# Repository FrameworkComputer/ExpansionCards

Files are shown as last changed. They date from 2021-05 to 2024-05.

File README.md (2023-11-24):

# Expansion Cards
Reference designs and documentation to create Expansion Cards for the Framework Laptop.
The Framework Laptop's Expansion Card system lets you choose exactly the ports you want
and which side you want them on.  We've built USB-C, USB-A, HDMI, DP, MicroSD, and Storage
Expansion Cards, but there is an entire world of other interesting ways to extend the
capabilities of a notebook.  We're releasing CAD to make it easy for you to develop your
own Expansion Cards.

Check out the Expansion Card section of the Framework Community for card ideas, support,
or just to show off what you're working on: https://community.frame.work/c/expansion-cards/developer-program/90

Note that you should build and test
development versions before committing a design based on this CAD to mass production.

MicrocontrollerExpansionCard

## License

Expansion Cards © 2021 by Framework Computer Inc is licensed under CC BY 4.0.
To view a copy of this license, visit http://creativecommons.org/licenses/by/4.0/

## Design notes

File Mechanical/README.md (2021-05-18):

# Expansion Card Mechanical CAD

## License

Expansion Cards © 2021 by Framework Computer Inc is licensed under CC BY 4.0.
To view a copy of this license, visit http://creativecommons.org/licenses/by/4.0/

## Files

There are a few variants of mechanical CAD that we have released:

 - OpenSCAD - This is a parametric model using OpenSCAD (https://openscad.org),
   designed to be easy to edit and 3D print.
   
 - Printable - These are 2D drawings and 3D CAD of an lid-less card enclosure
   that is designed to be easy to either 3D print, CNC, or injection mold.
   There is a version designed for use of self-tapping M2 screws, and also a
   version that can accomodate M2 threaded inserts.
   
 - Retrofit - This is a 2D drawing for a PCB that can be retrofit into existing
   Expansion Card cards sold by Framework.
   

## Getting Expansion Card Enclosures Fabricated

We've designed the enclosures to be printable on home 3D printers using PLA filament.

If you don't have a 3D printer, it's also easy to order enclosures from the various
printing services that are out there.  Because Expansion Cards are tiny, it is 
extremely inexpensive to get cards printed.  We haven't used all of the services below,
but these are some of the popular ones:
 - Shapeways (https://www.shapeways.com/) - HP MJF material
 - Hubs (https://www.hubs.com/) - HP MJF material (has a minimum order quantity)
 - Treatstock (https://www.treatstock.com/) - Range of materials, including PLA

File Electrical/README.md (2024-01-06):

# Expansion Card Electrical CAD

## License

Expansion Cards © 2021 by Framework Computer Inc is licensed under CC BY 4.0.
To view a copy of this license, visit http://creativecommons.org/licenses/by/4.0/

## Files

 - KiCad_templates - These are templates with the PCB outline and some basic components
   to let you get started with a card design quickly.  The Expansion_Card template
   is designed to be used with the 3D printable enclosures in the Mechanical folder.
   The Expansion_Card_Retrofit template is smaller and designed to fit into the existing
   Expansion Card enclosures like the DP Expansion Card's.  You can copy the folders to
   the default template directory: https://docs.kicad.org/5.0/en/kicad/kicad.html#template_locations
 - Microcontroller - A reference project using a SAMD21 Microcontroller with some pin
   headers broken out.  We've found Preci-Dip 8FM-78-0010-02-146 headers to fit well within the
   size constraints.  **Note:** We've built and done basic validation on an older version
   of this design, but the version currently in this repository is untested.
   

## Fabrication and Assembly

The templates and reference designs currently in this repository are basic, 2-layer, USB 2.0 designs.
This means the requirements around fabrication and assembly are pretty minimal.  Most PCB makers
and assemblers will be able to handle this.  We've listed a few popular ones below for reference.
Note that these are not necessarily vetted by Framework.

Note that there are pads next to the USB-C plug for manual soldering for additional strength.
You'll have to specify that to your assembler or hand solder that yourself.

PCB Only
 - OSHPark (https://oshpark.com/)

PCB+Assembly
 - Seeed (https://www.seeedstudio.com/fusion_pcb.html)
 - PCBWay (https://www.pcbway.com/pcb-assembly.html)
 - Macrofab (https://macrofab.com/)
 - Circuithub (https://circuithub.com/)

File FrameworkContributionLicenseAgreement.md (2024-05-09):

# Contribution License Agreement

This Contribution License Agreement (“Agreement”) is agreed to by the party signing (“You”), and conveys certain license rights to Framework Computer Inc and its affiliates (“Framework”) for Your contributions to Framework open source projects. This Agreement is effective as of the latest signature date.

1. Definitions.

   “Code” means the computer software code, whether in human-readable or machine-executable form, that is delivered by You to Framework under this Agreement.

   “Project” means any of the projects owned or managed by Framework in which software is offered under a license approved by the Open Source Initiative (OSI) (www.opensource.org) and documentation offered under an OSI or a Creative Commons license (https://creativecommons.org/licenses).

   “Submit” is the act of uploading, submitting, transmitting, or distributing code or other content to any Project, including but not limited to communication on electronic mailing lists, source code control systems, and issue tracking systems that are managed by, or on behalf of, the Project for the purpose of discussing and improving that Project, but excluding communication that is conspicuously marked or otherwise designated in writing by You as “Not a Submission.”

   “Submission” means the Code and any other copyrightable material Submitted by You, including any associated comments and documentation.

2. Your Submission. You must agree to the terms of this Agreement before making a Submission to any Project. This Agreement covers any and all Submissions that You, now or in the future (except as described in Section 4 below), Submit to any Project.

3. Originality of Work. You represent that each of Your Submissions is entirely Your original work. Should You wish to Submit materials that are not Your original work,You may Submit them separately to the Project if You (a) retain all copyright and license information that was in the materials as You received them, (b) in the description accompanying Your Submission, include the phrase “Submission containing materials of a third party:” followed by the names of the third party and any licenses or other restrictions of which You are aware, and (c) follow any other instructions in the Project’s written guidelines concerning Submissions.

4. Your Employer. References to “employer” in this Agreement include Your employer or anyone else for whom You are acting in making Your Submission, e.g. as a contractor, vendor, or agent. If Your Submission is made in the course of Your work for an employer or Your employer has intellectual property rights in Your Submission by contract or applicable law, You must secure permission from Your employer to make the Submission before signing this Agreement. In that case, the term “You” in this Agreement will refer to You and the employer collectively. If You change employers in the future and desire to Submit additional Submissions for the new employer,then You agree to sign a new Agreement and secure permission from the new employer before Submitting those Submissions.

5. Licenses.

   a. Copyright License. You grant Framework, and those who receive the Submission directly or indirectly from Framework, a perpetual, worldwide, non-exclusive, royalty-free, irrevocable license in the Submission to reproduce, prepare derivative works of, publicly display, publicly perform, and distribute the Submission and such derivative works, and to sublicense any or all of the foregoing rights to third parties.

   b. Patent License. You grant Framework, and those who receive the Submission directly or indirectly from Framework, a perpetual, worldwide, non-exclusive, royalty-free, irrevocable license under Your patent claims that are necessarily infringed by the Submission or the combination of the Submission with the Project to which it was Submitted to make, have made, use, offer to sell, sell and import or otherwise dispose of the Submission alone or with the Project.

   c. Other Rights Reserved. Each party reserves all rights not expressly granted in this Agreement. No additional licenses or rights whatsoever (including, without limitation, any implied licenses) are granted by implication, exhaustion, estoppel or otherwise.

6. Representations and Warranties. You represent that You are legally entitled to grant the above licenses.You represent that each of Your Submissions is entirely Your original work (except as You may have disclosed under Section 3). You represent that You have secured permission from Your employer to make the Submission in cases where Your Submission is made in the course of Your work for Your employer or Your employer has intellectual property rights in Your Submission by contract or applicable law. If You are signing this Agreement on behalf of Your employer, You represent and warrant that You have the necessary authority to bind the listed employer to the obligations contained in this Agreement. You are not expected to provide support for Your Submission, unless You choose to do so. UNLESS REQUIRED BY APPLICABLE LAW OR AGREED TO IN WRITING, AND EXCEPT FOR THE WARRANTIES EXPRESSLY STATED IN SECTIONS 3, 4, AND 6,THE SUBMISSION PROVIDED UNDER THIS AGREEMENT IS PROVIDED WITHOUT WARRANTY OF ANY KIND, INCLUDING, BUT NOT LIMITED TO, ANY WARRANTY OF NONINFRINGEMENT, MERCHANTABILITY, OR FITNESS FOR A PARTICULAR PURPOSE.

7. Notice to Framework. You agree to notify Framework in writing of any facts or circumstances of which You later become aware that would make Your representations in this Agreement inaccurate in any respect.

8. Information about Submissions. You agree that contributions to Projects and information about contributions may be maintained indefinitely and disclosed publicly, including Your name and other information that You submit with Your Submission.

9. Governing Law/Jurisdiction. This Agreement is governed by the laws of the State of California, and the parties consent to exclusive jurisdiction and venue in the federal courts sitting in San Francisco County, California, unless no federal subject matter jurisdiction exists, in which case the parties consent to exclusive jurisdiction and venue in the Superior Court of California. The parties waive all defenses of lack of personal jurisdiction and forum non-conveniens.

10. Entire Agreement/Assignment. This Agreement is the entire agreement between the parties, and supersedes any and all prior agreements, understandings or communications, written or oral, between the parties relating to the subject matter hereof. This Agreement may be assigned by Framework.

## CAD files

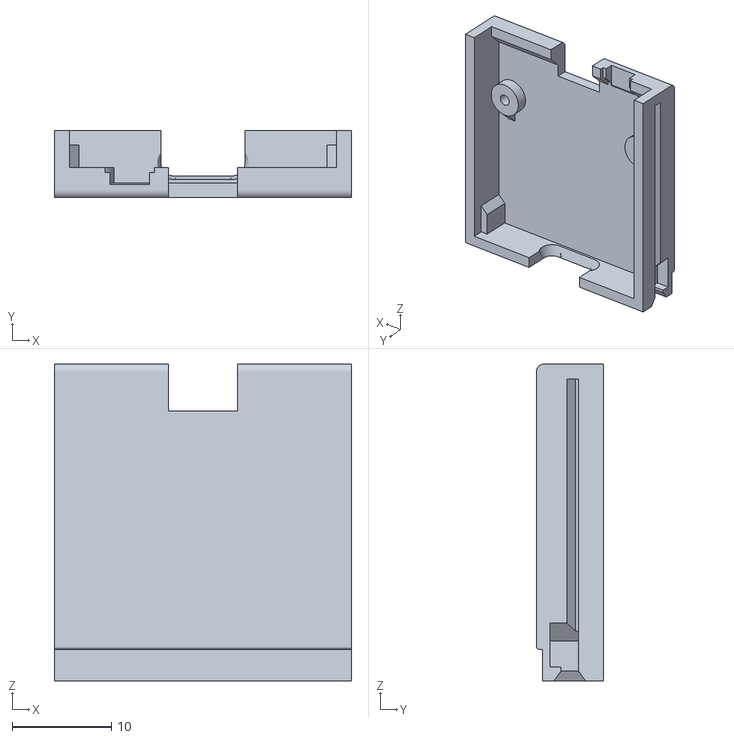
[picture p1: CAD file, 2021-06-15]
Mechanical/OpenSCAD/MicrocontrollerHousing.stl
30.0 x 6.80 x 32.0

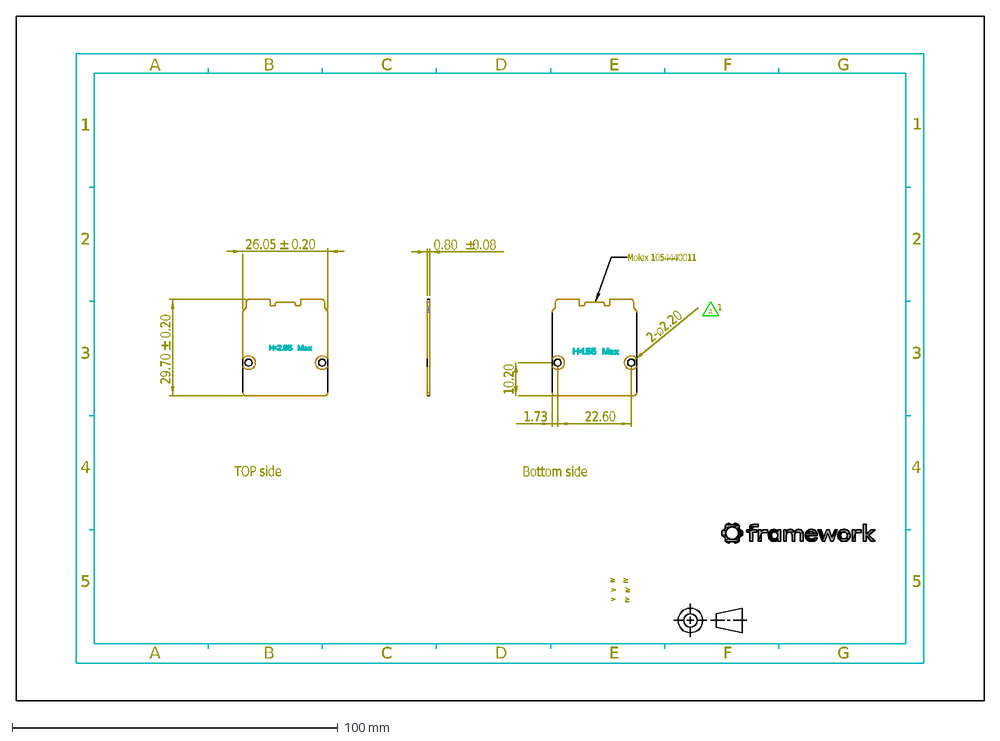
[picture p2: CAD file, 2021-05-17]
Mechanical/Printable/2D/ExpansionCard_Printable_M2.dxf
5
4
A
B
C
3
2
1
D
E
F
G
26.05
0.20
29.70
0.80
0.08
10.20
1.73
22.60
TOP side
Bottom side
Molex 1054440011

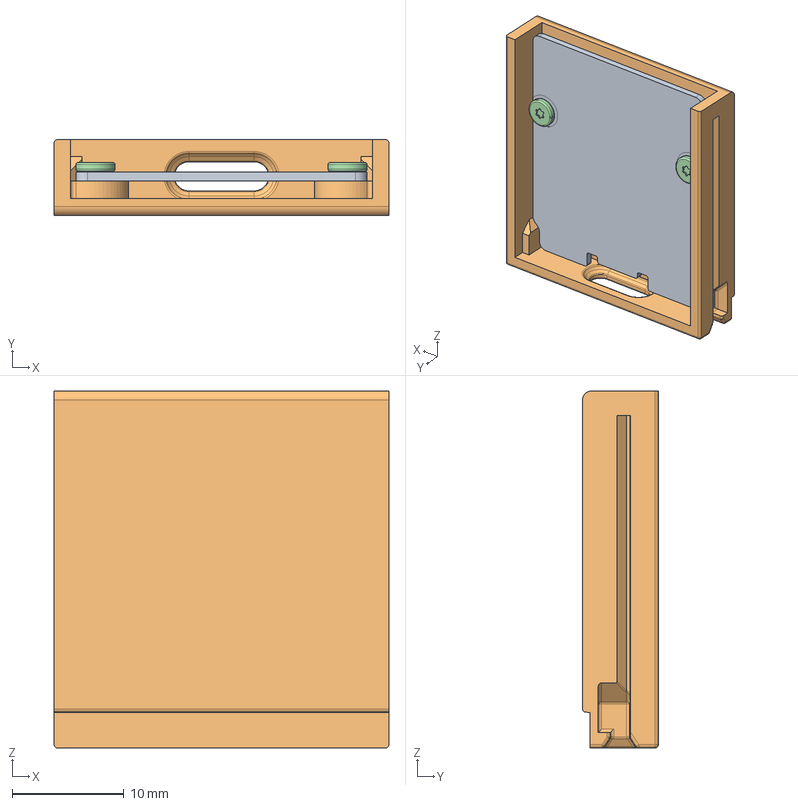
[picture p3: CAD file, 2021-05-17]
Mechanical/Printable/3D/ExpansionCard_ThreadedInsert.stp
30.0 x 6.80 x 32.0 mm
FW_EXP_1USBC_FRAME_CLIP_BC_229_
NUT_M2X1-6L_2 x 2
STAR_SCREW_M2X3L_298_2 x 2

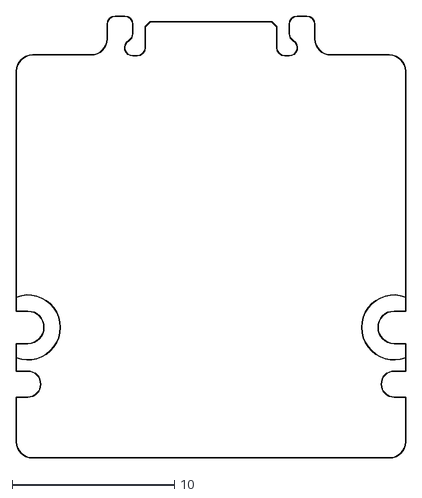
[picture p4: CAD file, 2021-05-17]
Mechanical/Retrofit/2D/ExpansionCard_Retrofit_Outline.dxf
24.0 x 27.2

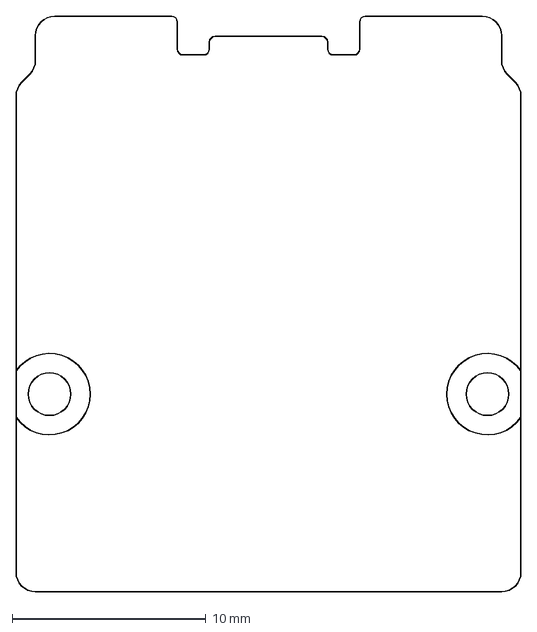
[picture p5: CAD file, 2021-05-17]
Mechanical/Printable/2D/ExpansionCard_Printable_Outline.dxf
26.1 x 29.7 mm

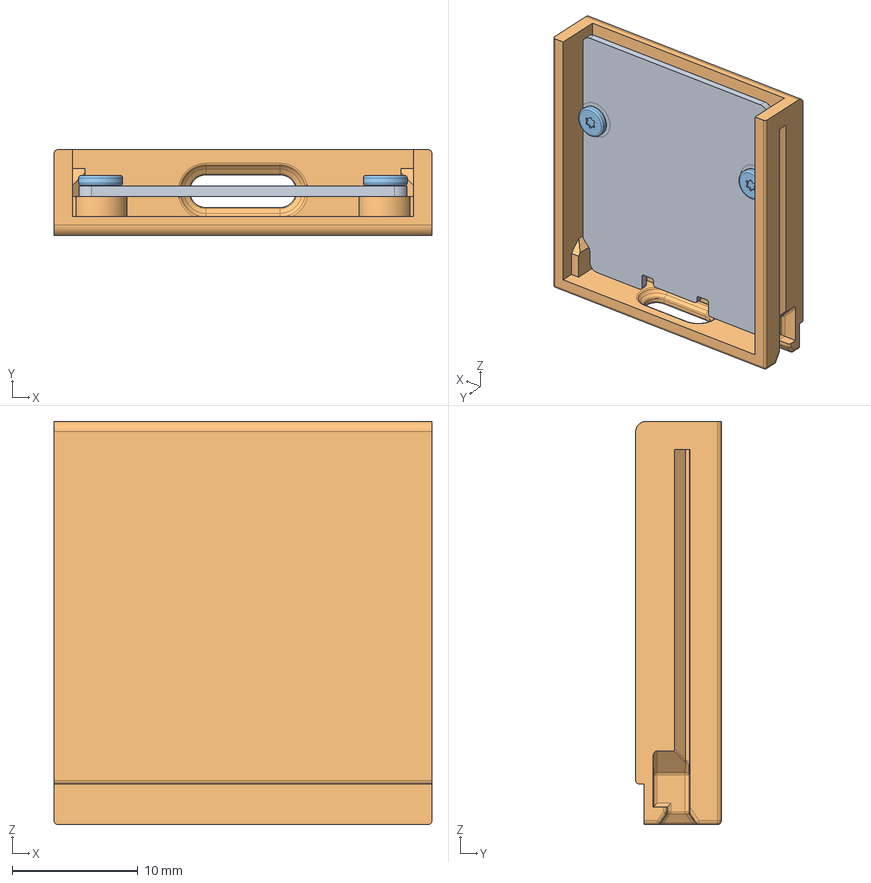
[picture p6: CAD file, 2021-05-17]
Mechanical/Printable/3D/ExpansionCard_SelfTapping.stp
30.0 x 6.80 x 32.0 mm
FW_EXP_1USBC_FRAME_CLIP_BC_229_
STAR_SCREW_M2X3L_298_1 x 2

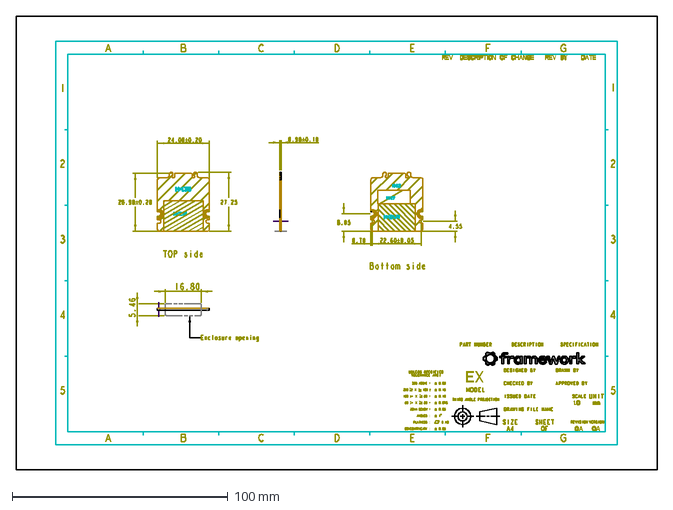
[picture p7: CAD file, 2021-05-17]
Mechanical/Retrofit/2D/ExpansionCard_Retrofit.dxf
297.0 x 210.0 mm

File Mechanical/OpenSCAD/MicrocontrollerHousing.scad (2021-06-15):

// Microcontroller Housing
//  An enclosure to use with the Microcontroller Expansion Card
//  reference design.
//
//  See https://frame.work for more information about Framework products and
//  additional documentation around Expansion Cards.

// Microcontroller Housing © 2021 by Nirav Patel at Framework Computer Inc
// is licensed under Attribution 4.0 International. 
// To view a copy of this license, visit http://creativecommons.org/licenses/by/4.0/

include <ExpansionCard.scad>;

gap = 0.5;
jst_w = 6.0; // JST SH 4-pin receptacle
jst_d = 4.25;
b3u_offset = 5.596+side_wall+pcb_gap;
b3u_w = 3.0; // Omron B3U-3100 button
b3u_pad_w = 4.0;
b3u_h = 1.2;
b3u_d = 2.5;
rib_w = 1;

module microcontroller_housing(make_printable = true) {
    difference() {
        expansion_card_base(open_end = false, make_printable = make_printable, pcb_mount="boss");
        translate([side_wall, 0, pcb_h]) cube([base[0]-side_wall*2, side_wall, base[2]]);
        // Cut out for bottom mount JST SH connector
        translate([base[0]/2-jst_w/2-gap, 0, 0]) cube([jst_w+gap*2, jst_d+gap, base[2]]);
        // Cut out for bottom mount reset switch
        translate([b3u_offset-b3u_w/2-gap, 0, pcb_h-b3u_h-gap]) cube([b3u_w+gap*2, b3u_d+gap, base[2]]);
        translate([b3u_offset-b3u_pad_w/2-gap, 0, pcb_h-gap]) cube([b3u_pad_w+gap*2, b3u_d+gap, base[2]]);
    }

    if (make_printable) {
        // Add ribs for printability
        translate([base[0]/2-jst_w/2-gap-rib_w/2, side_wall, 0]) rib(rib_w, pcb_h);
        translate([base[0]*0.75+jst_w*0.25+gap/2, side_wall, 0]) rib(base[0]/2-jst_w/2-gap, pcb_h);
        translate([b3u_offset-b3u_w/2-gap-rib_w/2, side_wall, 0]) rib(rib_w, pcb_h-gap);
        translate([b3u_offset+b3u_w/2+gap+rib_w/2, side_wall, 0]) rib(rib_w, pcb_h-gap);
        translate([b3u_offset/2-b3u_pad_w/4-gap/2, side_wall, 0]) rib(b3u_offset-b3u_pad_w/2-gap, pcb_h);
        translate([b3u_offset+b3u_pad_w/2+gap+rib_w/2, side_wall, 0]) rib(rib_w, pcb_h);
    }
}

rotate([-90, 0, 0]) translate([0, -base[1], 0]) microcontroller_housing(true);

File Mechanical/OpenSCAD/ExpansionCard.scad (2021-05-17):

// Parametric Expansion Card
//  An OpenSCAD implementation of a basic enclosure of an Expansion Card for
//  use with Framework products like the Framework Laptop.
//
//  See https://frame.work for more information about Framework products and
//  additional documentation around Expansion Cards.

// Parametric Expansion Card © 2021 by Nirav Patel at Framework Computer LLC
// is licensed under Attribution 4.0 International. 
// To view a copy of this license, visit http://creativecommons.org/licenses/by/4.0/

// The basic dimensions of an Expansion Card
base = [30.0, 32.0, 6.8];
// The default wall thickness
side_wall = 1.5;

// Size and location of the typical PCB
pcb_gap = 0.5;
pcb = [26.0, 30.0, 0.8];
pcb_h = 3.05;

// USB-C plug dimensions
usb_c_r = 1.315;
usb_c_w = 5.86+usb_c_r*2;
usb_c_h = 2.2;

rail_h = 4.25; // to top of rail

// Boss locations matching the other Framework Expansion Cards
boss_y = 10.5;
boss_x = 3.7;

// The rail cutout in the sides of the card
module rail(make_printable) {
    rail_depth = 0.81;
    rail_flat_h = 0.32;
    
    mirror([0, 1, 0]) {
        
        // The rail that holds the card
        bottom_angle = 43.54;
        difference() {
            union() {
                translate([rail_depth, 0, -rail_flat_h]) rotate([0, 180+bottom_angle, 0]) cube([2, base[1]-side_wall, 2]);
                translate([-2+rail_depth, 0, -rail_flat_h]) cube([2, base[1]-side_wall, rail_flat_h]);
            }
            translate([-5+rail_depth, 0, 0]) cube([5, base[1]-side_wall, 5]);
        }
    
        pyramid_b = 3.23*sqrt(2);
        pyramid_t = 1.75*sqrt(2);
        pyramid_h = 1.0;
        pyramid_inset = 1.3+0.5;
        pyramid_step = 3.06;
        
        // The ramps to make slotting into the latch smooth
        translate([-1.75/2+pyramid_inset, 0, -1.75/2]) rotate([-90, 0, 0]) rotate([0, 0, 45]) { 
            cylinder(r1 = pyramid_b/2, r2 = pyramid_t/2, h = pyramid_h, $fn=4);
            cylinder(r = pyramid_t/2, h = pyramid_step+pyramid_h, $fn=4);
            translate([-0.1, 0.1, 0])cylinder(r = pyramid_t/2, h = pyramid_step+pyramid_h, $fn=4);
        }
        
        latch_l = 2.67;
        latch_d = pyramid_inset;
        latch_h = 2.85;
        latch_wall = 1.39;
        
        // The pocket that the latch bar drops into, including a 45 degree cut for printability
        translate([0, latch_wall, -latch_h]) cube([latch_d, latch_l, latch_h]);
        if (make_printable) {
            translate([latch_d, latch_wall+latch_l, -latch_h]) rotate([0, 0, -180+45]) translate([0, -latch_l, 0]) cube([latch_d*2, latch_l, latch_h]);
        }
    }
}

// A simple 45 degree rib to improve printability
module rib(thickness, height) {
    translate([-thickness/2, 0, 0]) difference() {
        cube([thickness, height, height]);
        translate([-thickness/2, height, 0]) rotate([45, 0, 0]) cube([thickness*2, height*2, height*2]);
    }
}

// A simple cylinder cutout to fillet edges
module fillet(radius, length) {
    translate([length, 0, 0]) rotate([0, -90, 0]) difference() {
        cube([radius, radius, length]);
        translate([radius, radius, -1]) cylinder(h = length+2, r = radius, $fn = 64);
    }
}

// The cutout for the USB-C plug
module usb_c_cutout(open_top) {
    // The plug is "pushed in" by an extra 0.6 to account for 3d printing tolerances
    translate([-usb_c_w/2+usb_c_r, 7-10+0.6, usb_c_r]) rotate([-90, 0, 0]) union() {
        translate([0, usb_c_r, 0]) cylinder(r = usb_c_r, h = 10, $fn = 64);
        translate([usb_c_w-usb_c_r*2, usb_c_r, 0]) cylinder(r = usb_c_r, h = 10, $fn = 64);
        cube([usb_c_w-usb_c_r*2, usb_c_r*2, 10]);
        
        // Cutout for the pin side of the shell that expands out
        translate([0, usb_c_r, 0]) cylinder(r2 = usb_c_r, r1 = 3.84/2, h = 10-7.7, $fn = 64);
        translate([usb_c_w-usb_c_r*2, usb_c_r, 0]) cylinder(r2 = usb_c_r, r1 = 3.84/2, h = 10-7.7, $fn = 64);
        translate([usb_c_w/2-usb_c_r, usb_c_r, 0]) scale([1.8, 1, 1]) rotate([0, 0, 45]) cylinder(r2 = usb_c_r*sqrt(2), r1 = 3.84/2*sqrt(2), h = 10-7.7, $fn = 4);
        
        // If the card drops in from the top rather than sliding in from the front,
        // cut out a slot for the USB-C plug to drop into.
        if (open_top) {
            translate([-usb_c_r, -10+usb_c_r, 0]) cube([usb_c_w, 10, 10]);
        }
    }
}

// Quarter section of a sphere, used as a clip
module qsphere(radius = 1) {
    difference() {
        sphere(r = radius, $fn = 32);
        translate([-radius-1, -radius-1, -radius]) cube([radius*2+2, radius*2+2, radius]);
        translate([0, -radius-1, -radius-1]) cube([radius, radius*2+2, radius*2+2]);
    }
}

// The screw boss for the PCB, optionally with space for a threaded insert
module boss(radius, use_insert, make_printable) {
    difference() {
        cylinder(r = radius, h = pcb_h, $fn = 64);
        if (use_insert) {
            // Use threaded insert
            translate([0, 0, side_wall]) cylinder(r = 1.5, h = pcb_h, $fn = 64);
        } else {
            translate([0, 0, side_wall]) cylinder(r = 0.75, h = pcb_h, $fn = 64);
        }
    }
    
    // Add a rib for printability
    if (make_printable) {
        translate([0, radius-0.1, 0]) rib(1, pcb_h);
    }
}

// Incomplete implementation of a lid to use with this shell
module expansion_card_lid() {
    gap = 0.25;
    union() {
        translate([side_wall+gap, side_wall+gap, base[2]-side_wall]) cube([base[0]-side_wall*2-gap*2, base[1]-side_wall*2-gap*2, side_wall]);
        difference() {
            translate([base[0]/2-usb_c_w/2+gap, base[1]-side_wall-gap, usb_c_r+usb_c_h]) cube([usb_c_w-gap*2, side_wall+gap, base[2]-(usb_c_r+usb_c_h)]);
            translate([base[0]/2, base[1], usb_c_r+usb_c_h]) usb_c_cutout(false);
        }
    }
}
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

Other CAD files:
Mechanical/OpenSCAD/ExpansionCard.stl
Mechanical/Printable/3D/ExpansionCard_SelfTapping.stl
Mechanical/Printable/3D/ExpansionCard_ThreadedInsert.stl

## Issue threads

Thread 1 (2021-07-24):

What are the dimensions of the actual card (not the pcb)? / no mechanical drawings

ExplodingWaffle, 2021-07-24:
Saw the Framework on HN the other day, very interested. As someone who is into electronics, I'm in love with this whole "design your own expansion card" thing. However- there are a couple of snags I've ran into-

- It isn't immediately obvious how far the USB-C plug should stick out of the card. This would be very helpful info for using different parts for the USB connector, which is nice for flexibility (i'm thinking [this guy](https://www.adafruit.com/product/4932) should allow for taller components) and sourcing.

- There aren't any mechanical drawings of the card itself. The 3D files are great, but a diagram with all the critical external dimensions including stuff like the rail would be very handy for designing a case from scratch in whatever tool we want.

- How tall are the feet of the laptop (for any potential sticky outy bits)

This extra documentation would be awesome, I've got some ideas that would be really helped out.

trick2011, 2022-01-16:
This is such an important open issue. I might be interested with doing stuff with these cards and I've done PCB design professionally but with the limited amount of info it is more difficult than it has to be.

There should be more measurements in this repo. The above mentioned dimensions are missing/unclear but also the outer dimensions of the laptop bays are not provided.

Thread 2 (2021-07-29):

Yubikey type module

CorruptComputer, 2021-07-29:
Would it be possible to have a Yubikey-like module for this as well?

I'm thinking something like this could be used to store LUKS encryption keys for the SSD as well as any SSH keys a user may have.

Would make it convenient to keep in the laptop while you are using it, while not having the risk of damaging a USB port while walking about. Also as a security feature when away from the laptop, just take the module with you.

drewwestrick, 2021-09-20:
This is probably totally possible. Nitrokey is mostly open source and the firmware for the MCU they use, the STM32F103, is the link below. You could probably adapter their Nitrokey Pro hardware / MCU design into a Framework adapter (link also below).

https://github.com/Nitrokey/nitrokey-pro-hardware
https://github.com/Nitrokey/nitrokey-pro-firmware

eclecticc, 2023-09-04:
The community is a good place to discuss ideas for Expansion Cards: https://community.frame.work/c/developer-program/expansion-card/90

CorruptComputer, 2023-09-07:
Ah apologies, I didn't know that was where suggestions should go.

Just checked there and it looks like some folks have already made 3d-printable enclosures for Yubikeys, this is fantastic news for me. Thank you!

For reference in case anyone else is interested: https://community.frame.work/t/yubikey-5c-adapter/23157

Closed 2023-09-04.

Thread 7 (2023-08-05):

Add reference design with enlarged enclosure?

bmcdonnell, 2023-08-05:
Please consider sharing a reference design for larger enclosures, such as your [ethernet expansion card](https://frame.work/products/ethernet-expansion-card).

I don't personally have any plans to make one. I just thought it might be good for the community.

eodpunk, 2024-02-19:
This would be awesome. That way if we need to make a larger expansion card we can use its dimensions to have it fit in the existing expansion card storage boxes.

Montana1176, 2025-03-03:
Instead of making my own issue, I'm going to bump this one. Having the ethernet expansion card enclosure would be super nice for what i'm currently working on.

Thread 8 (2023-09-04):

Request: Add PDF plots of schematics to the Electrical projects

DeflateAwning, 2023-09-04:
It would be easier to preview what these projects are without cloning them if you put the plotted PDFs in the repo

eclecticc, 2023-09-04:
The Microcontroller has a pdf https://github.com/FrameworkComputer/ExpansionCards/blob/main/Electrical/Microcontroller/Microcontroller.pdf

The templates don't because the cards are blank.  They are really just mechanical outlines to avoid needing to draw the geometry yourself.

DeflateAwning, 2023-09-04:
Thank you

eclecticc, 2023-09-04:
Added PDFs for the others as well to make that clearer.

DeflateAwning, 2023-09-04:
Thanks!

(in commit: https://github.com/FrameworkComputer/ExpansionCards/commit/ee260d97721e38d13001eb6d065263db58813266)

Closed 2023-09-04.

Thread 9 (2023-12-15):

3D Models for Printing Expansion Cards are backward.

tekchip, 2023-12-15:
The 3D models at https://github.com/FrameworkComputer/ExpansionCards/tree/main/Mechanical are backward. The latch hooks should face back, opposite of the wall with the plug hole, and the lip to get leverage for removal is also at the same end as everything else.

I discovered this after getting a 3D print without modifying any files, just sending it off.

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

eclecticc, 2023-12-15:
Not sure if I am following your description, but the 3D file looks correct.  The latches are on the same side as the USB-C plug.  The open end is open to give you flexibility to put what you would like there.

tekchip, 2023-12-15:
> Not sure if I am following your description, but the 3D file looks correct.  The latches are on the same side as the USB-C plug.  The open end is open to give you flexibility to put what you would like there.

For real? I drew a diagram. Look at my photos of the part I had printed next to an actual expansion card.

The closed side with a port hole should face out from the laptop body. The latch clip and external groove to grip the card for removal should be at the opposite end.

In the 3d model all those things are on the same side. That's not how it's supposed to work.

eclecticc, 2023-12-15:
No, the closed side with the hole is the side that gets inserted into the laptop.  The hole is for the USB-C plug to go through to plug into the Mainboard.  You can see that a regular mass production Expansion Card works the same way.

tekchip, 2023-12-15:
Apologies, I see what you're saying now. That side is intended to be the internal C connection. The other is to be modified for whatever.

Perhaps a different issue needs to be addressed then. It's possible I missed it but it was not clear to me, a DIYer, that that was the intended orientation of the tray and that a part is intentionally absent.

Perhaos there's a way to label the image examples or something so it's visually clear which direction relative to the laptop the model is oriented? Haven't spent much time thinking on it having just realized what's going on there.

Closed 2023-12-15.

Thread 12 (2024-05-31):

Expansion Card Slot Files needed

fantastic-engineering, 2024-05-31:
Hello Framework Team!
I please require a cad model and / or dimensions for the slot that the expansion card goes into.

Without it, we only have half the system to work with and I think the idea is so great that it should not be confined to be only used in your laptops, but in accessories as well. For that it is necessary to be able to have the slots for laptop 13 and / or laptop 16 as model to drop into any design to make it compatible with your cards.

I also heard, some people would like to have not only the cad file or the card but also detailed drawings of it to determine things like USB-C connector stickout, floor clearance when in the laptop and the like.
Please provide these informations so the expansion card system can grow to its full potential.

Thank you for sharing!

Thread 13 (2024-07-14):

Upstream the Framework logo

phodina, 2024-07-14:
Hi,
thanks for providing the templates. I've created MR for the logo to the Kicad footprints.

Feel free to check it out!

https://gitlab.com/kicad/libraries/kicad-footprints/-/merge_requests/3721

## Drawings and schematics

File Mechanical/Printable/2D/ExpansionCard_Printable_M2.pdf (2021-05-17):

1

A | B | C

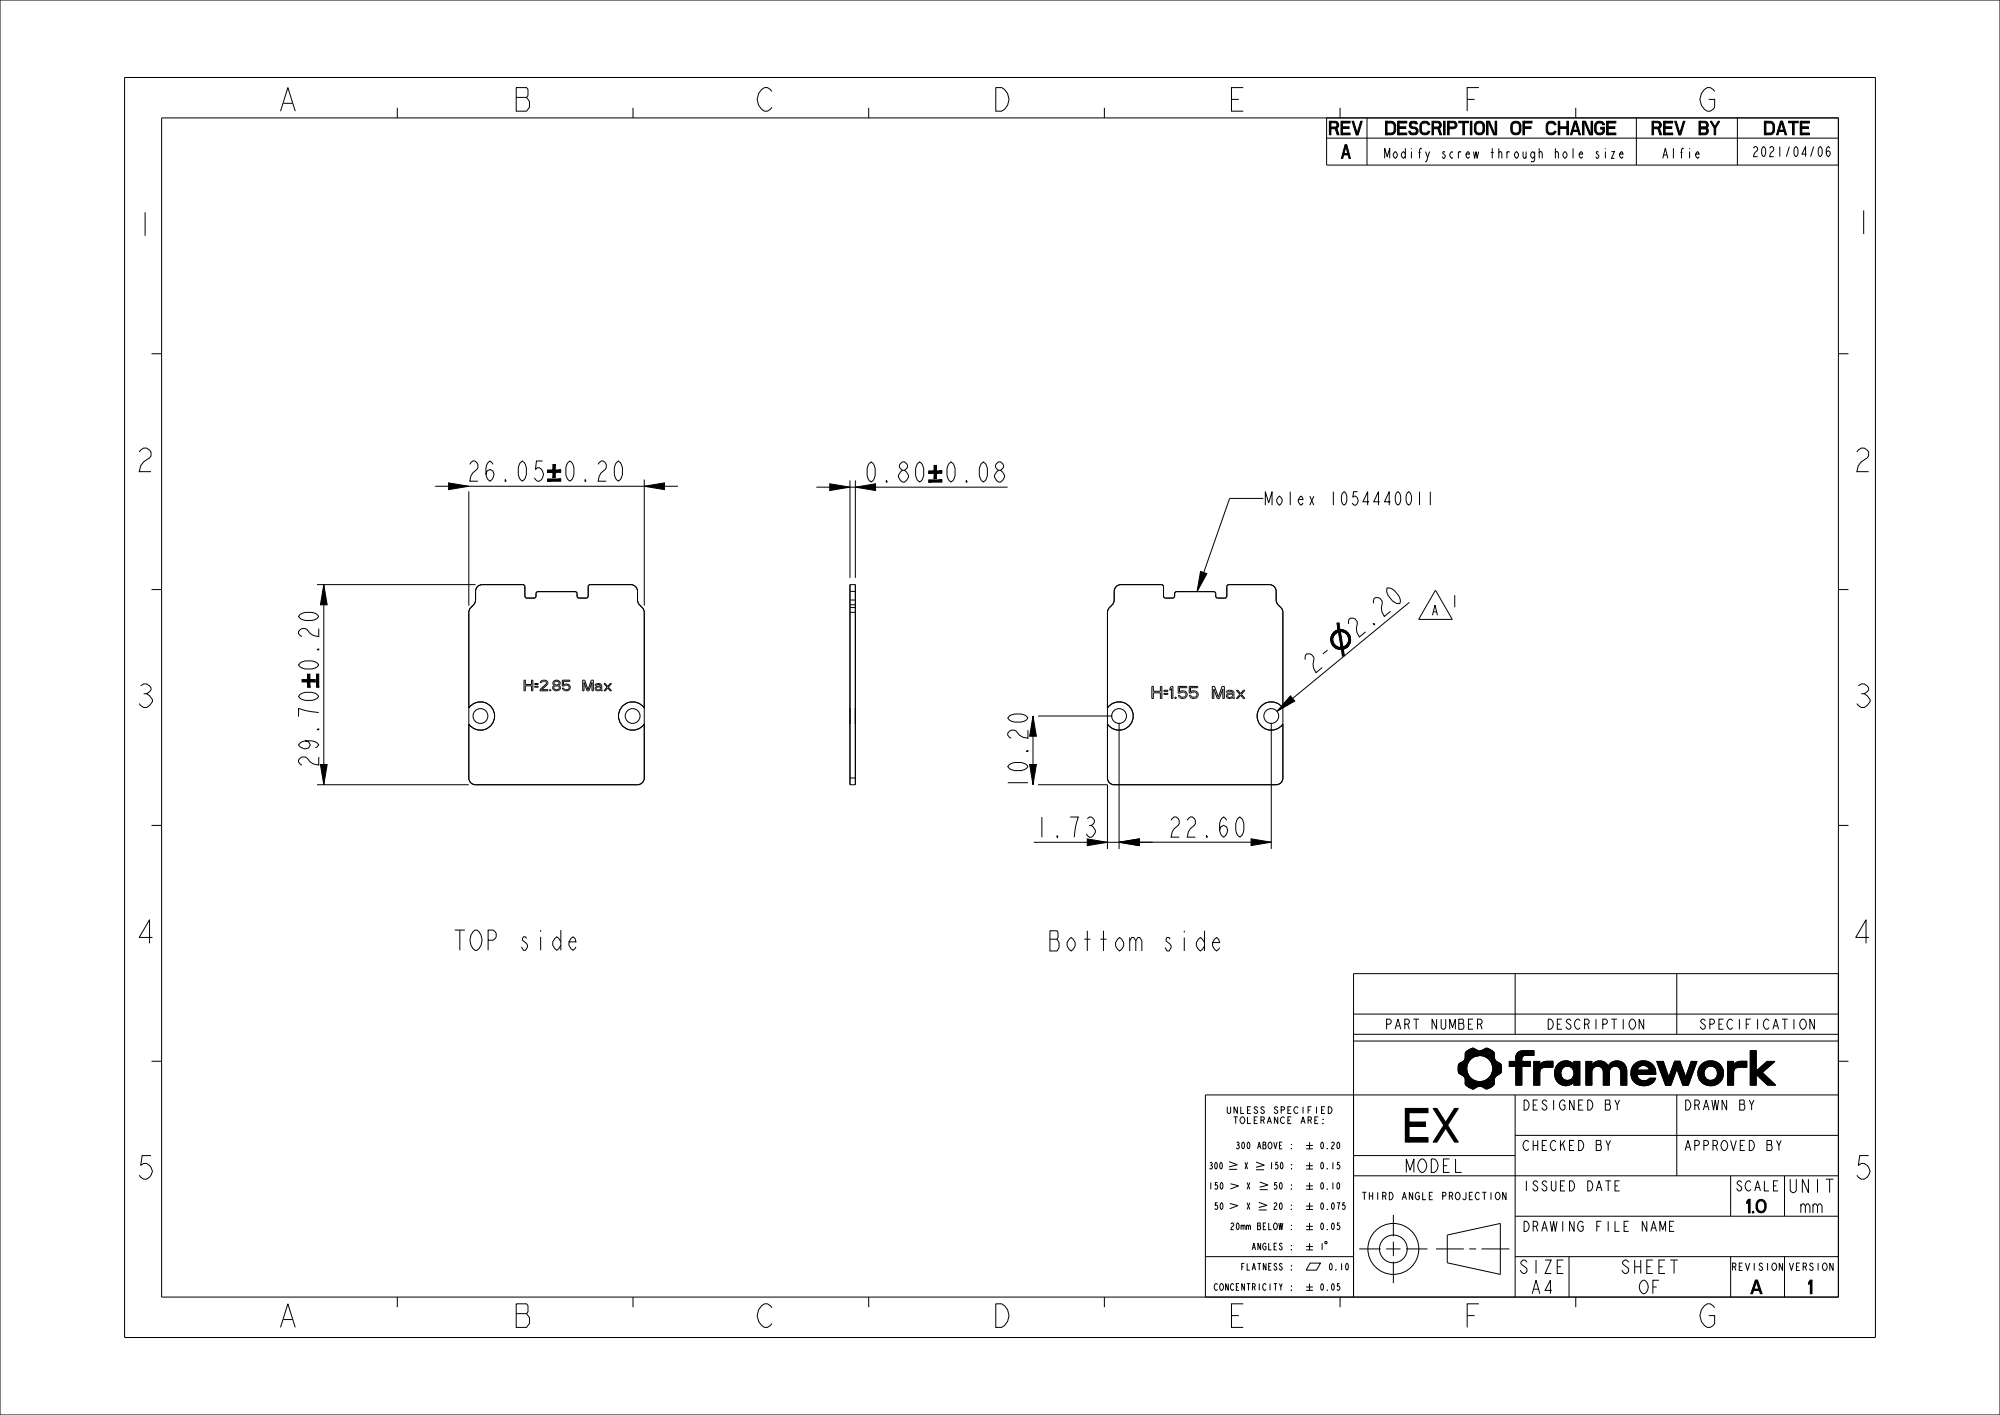
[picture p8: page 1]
PART NUMBER; DESCRIPTION; SPECIFICATION; MODEL; THIRD ANGLE PROJECTION; ISSUED DATE; SCALE UNIT; SIZE; SHEET; REVISION VERSION; REV DESCRIPTION OF CHANGE; REV BY; DATE; Modify screw through hole size; Alfie; FLATNESS :; CONCENTRICITY :; TOP side; Bottom side; Molex 1054440011

UNLESS SPECIFIED TOLERANCE ARE: 300 ABOVE : 300 X 150 : 150 X 50 : 50 X 20 : 20mm BELOW : ANGLES : | EX | DESIGNED BY | DRAWN BY

CHECKED BY | APPROVED BY

DRAWING FILE NAME

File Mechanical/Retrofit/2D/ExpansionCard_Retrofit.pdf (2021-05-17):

1

A | B | C

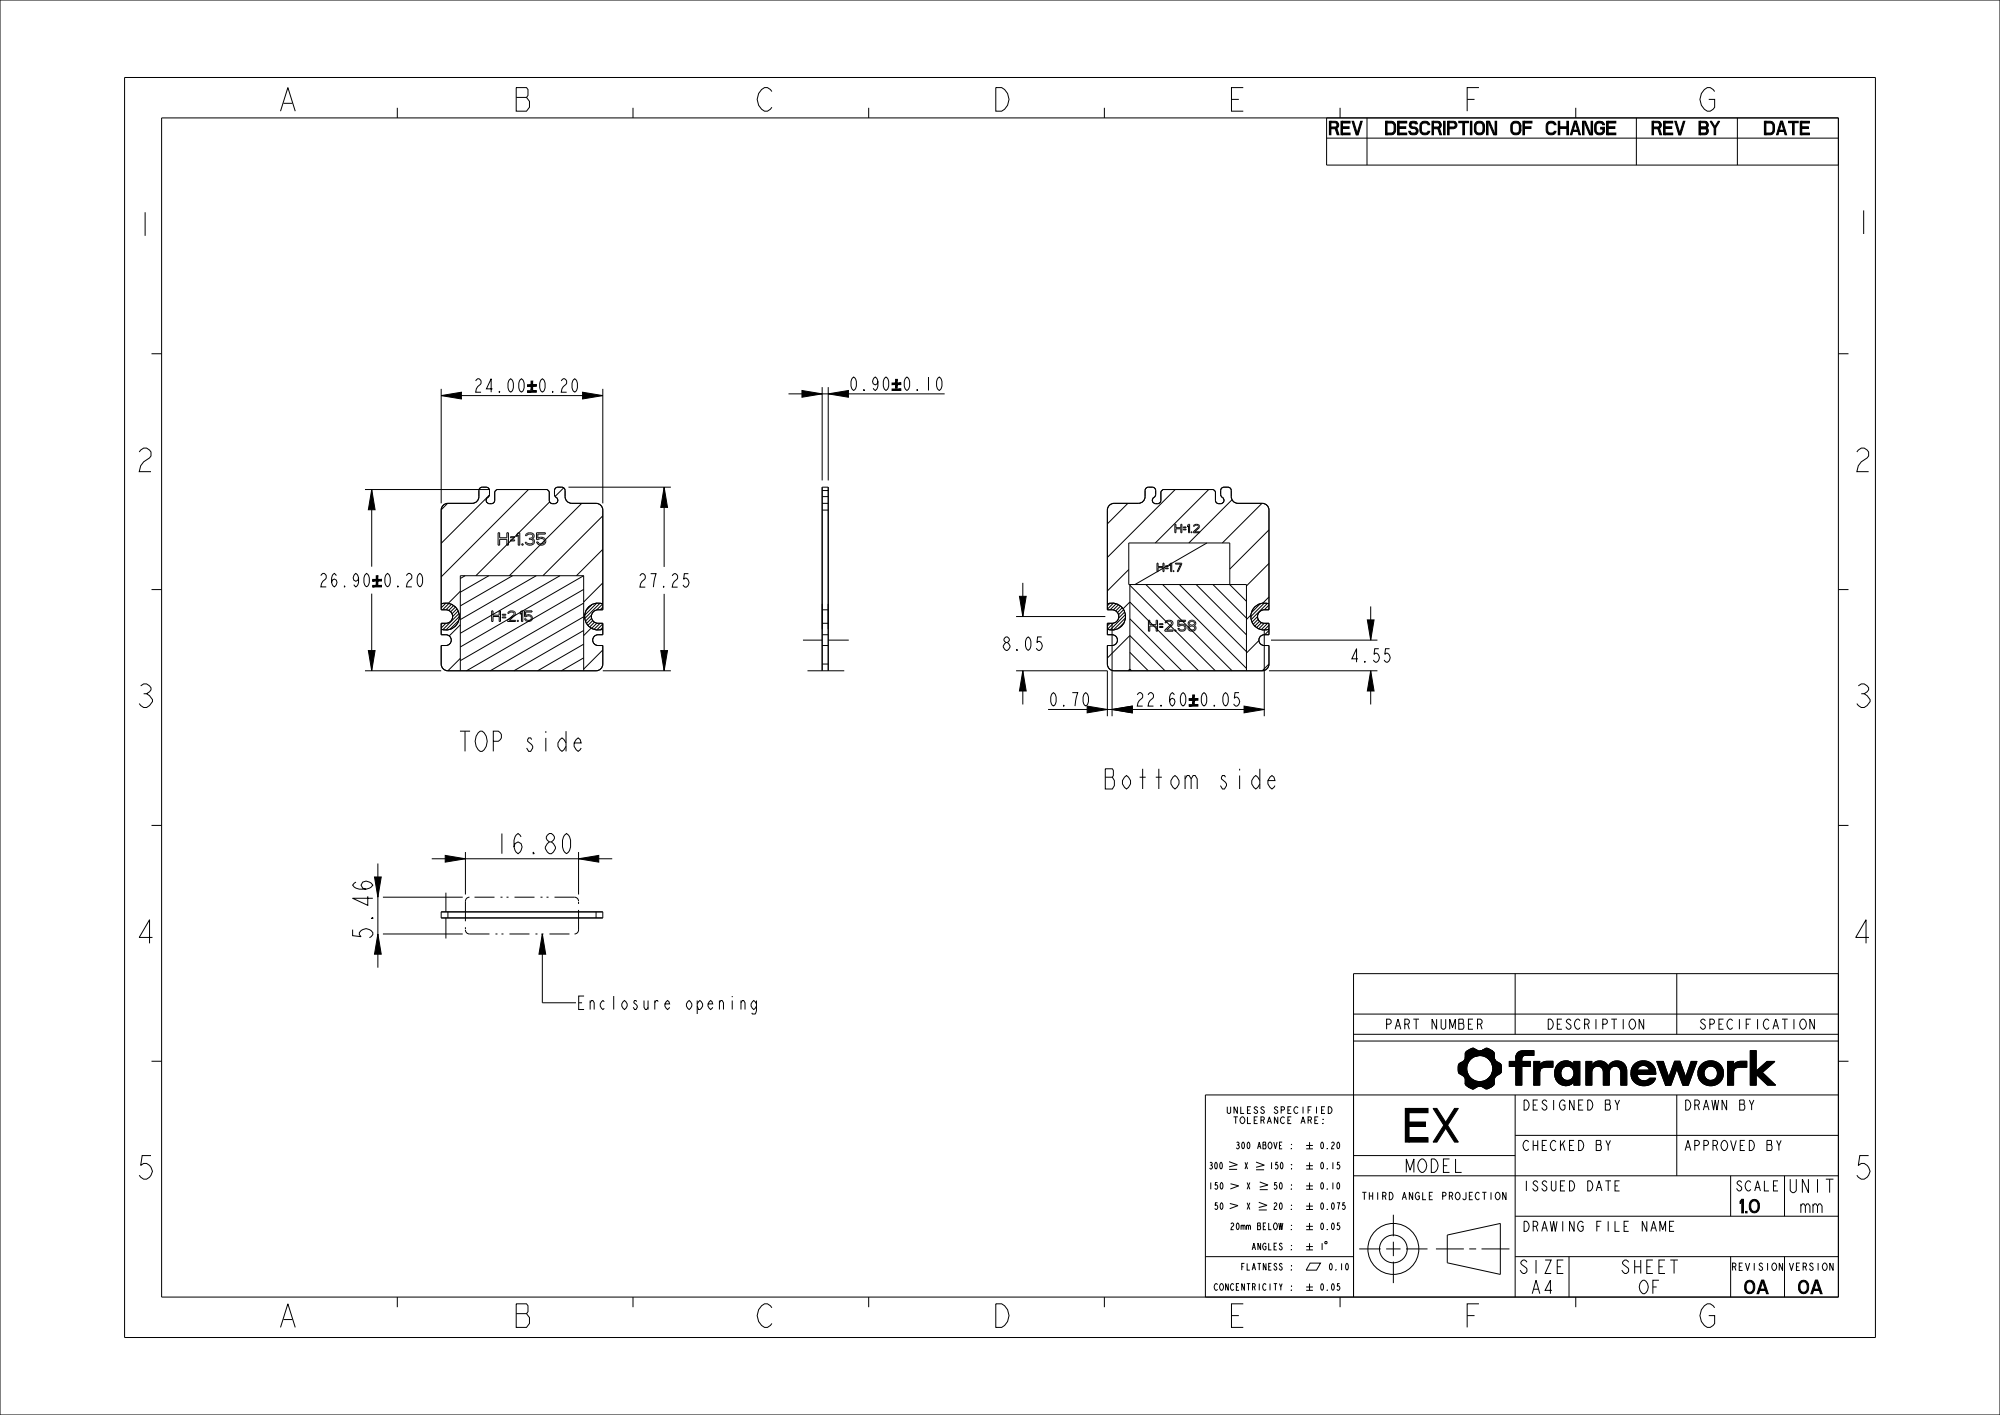
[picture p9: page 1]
PART NUMBER; DESCRIPTION; SPECIFICATION; MODEL; THIRD ANGLE PROJECTION; ISSUED DATE; SCALE UNIT; SIZE; SHEET; REVISION VERSION; REV DESCRIPTION OF CHANGE; REV BY; DATE; FLATNESS :; CONCENTRICITY :; TOP side; Bottom side; Enclosure opening

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

CHECKED BY | APPROVED BY

DRAWING FILE NAME

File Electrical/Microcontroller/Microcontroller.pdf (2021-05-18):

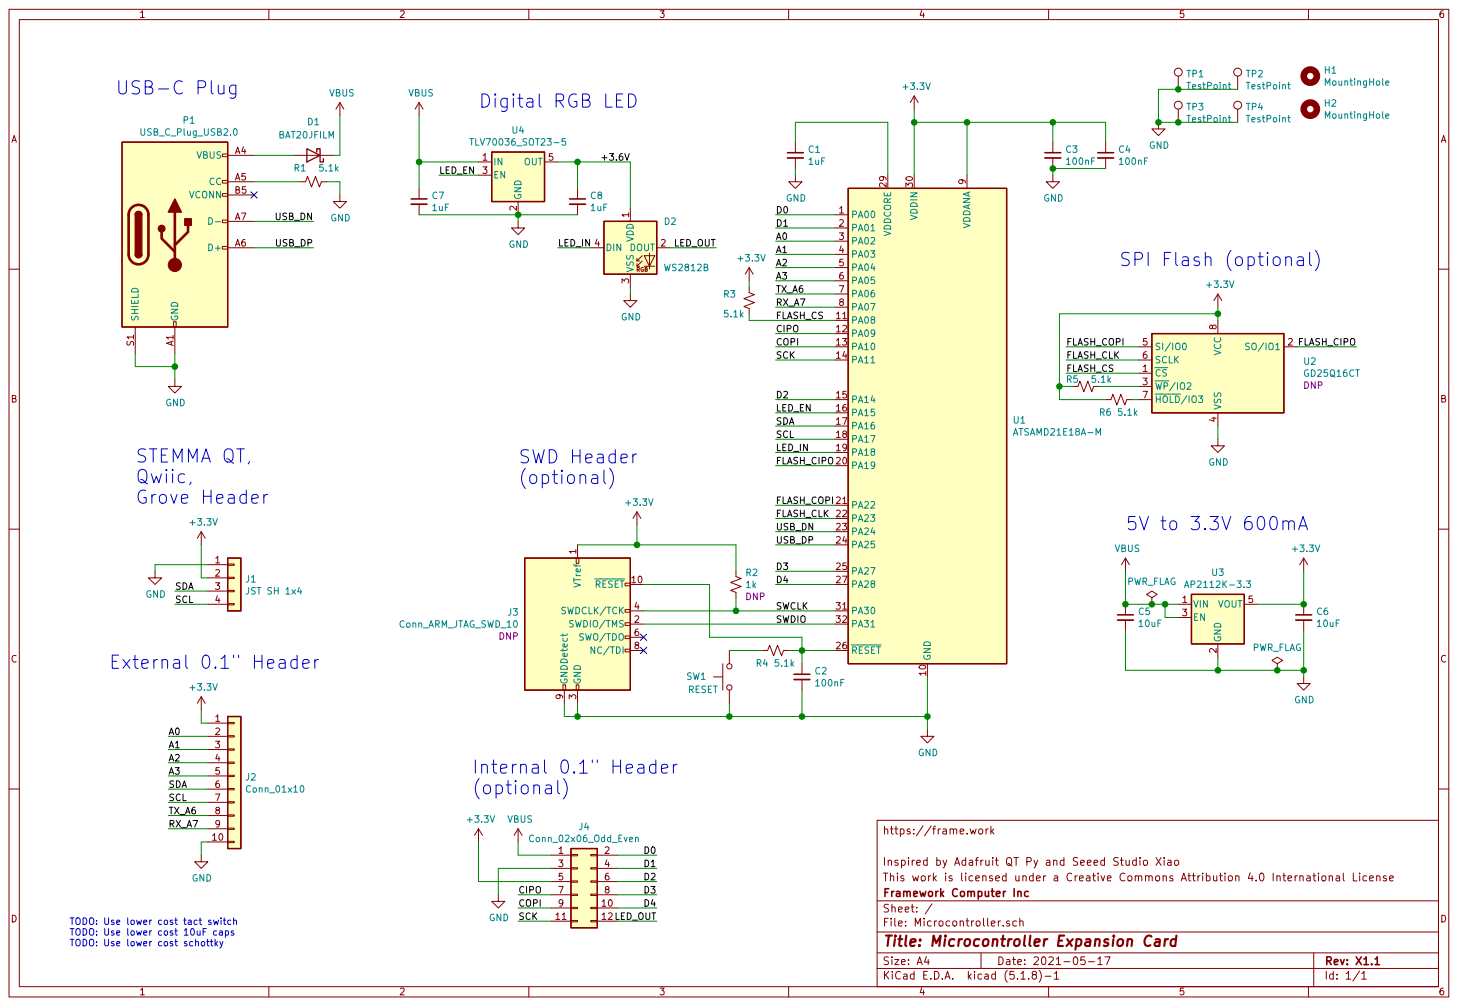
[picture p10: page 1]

3 DIN 4 D2WS2812B GND A1 VBUS A4 CC A5 D+ A6 D- A7 VCONN B5 SHIELD S1 P1 USB_C_Plug_USB2.0 GND

4 SI/IO0 5 SCLK 6 HOLD/IO3 7 VCC

3 SWDCLK/TCK 4 SWO/TDO 6 NC/TDI 8 GNDDetect 9

Inspired by Adafruit QT Py and Seeed Studio Xiao
File: Microcontroller.sch Sheet: / Framework Computer Inc This work is licensed under a Creative Commons Attribution 4.0 International License

7 | 8 D3

TODO: Use lower cost tact switch TODO: Use lower cost 10uF caps

Id: 1/1 Title: Microcontroller Expansion Card

TODO: Use lower cost schottky

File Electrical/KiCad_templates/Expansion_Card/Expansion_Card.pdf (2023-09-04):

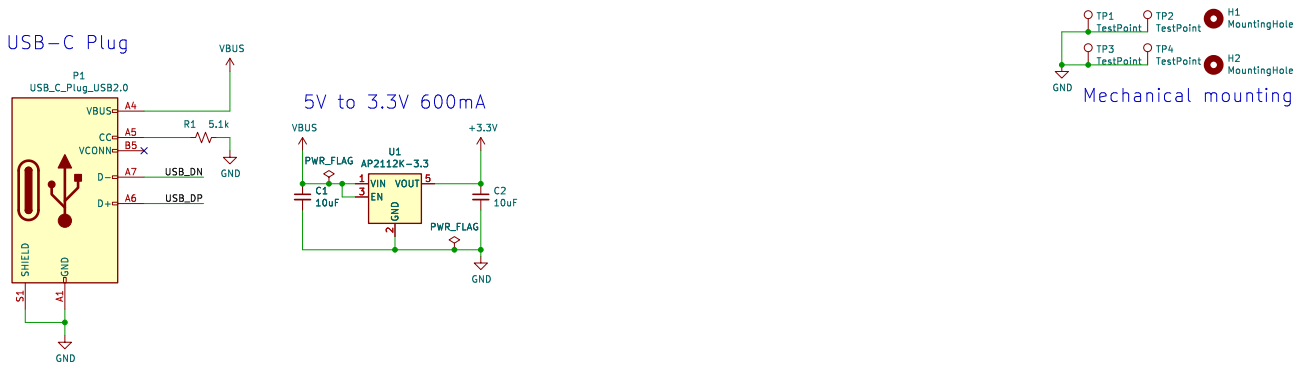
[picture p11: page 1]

Id: 1/1 Title: Expansion Card Template

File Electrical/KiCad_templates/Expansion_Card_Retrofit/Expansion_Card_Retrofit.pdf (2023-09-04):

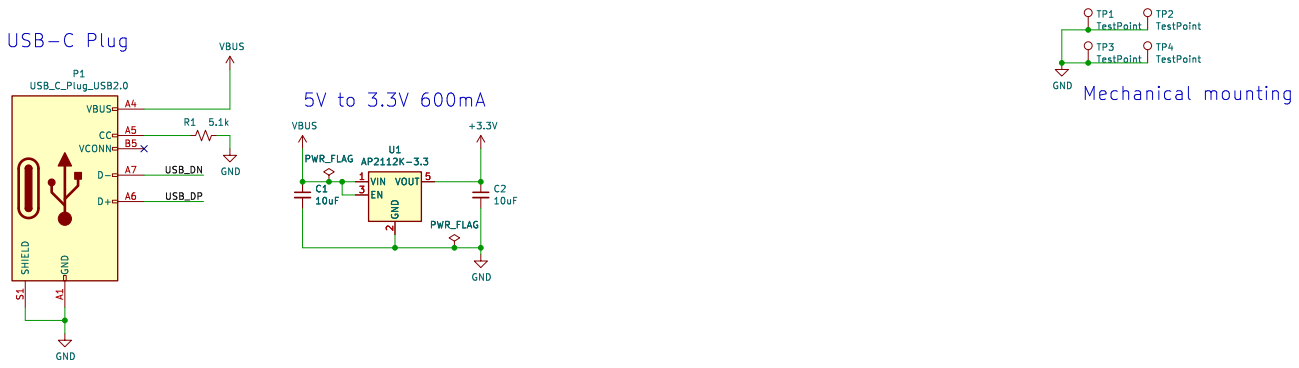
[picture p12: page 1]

Id: 1/1 Title: Expansion Card Template

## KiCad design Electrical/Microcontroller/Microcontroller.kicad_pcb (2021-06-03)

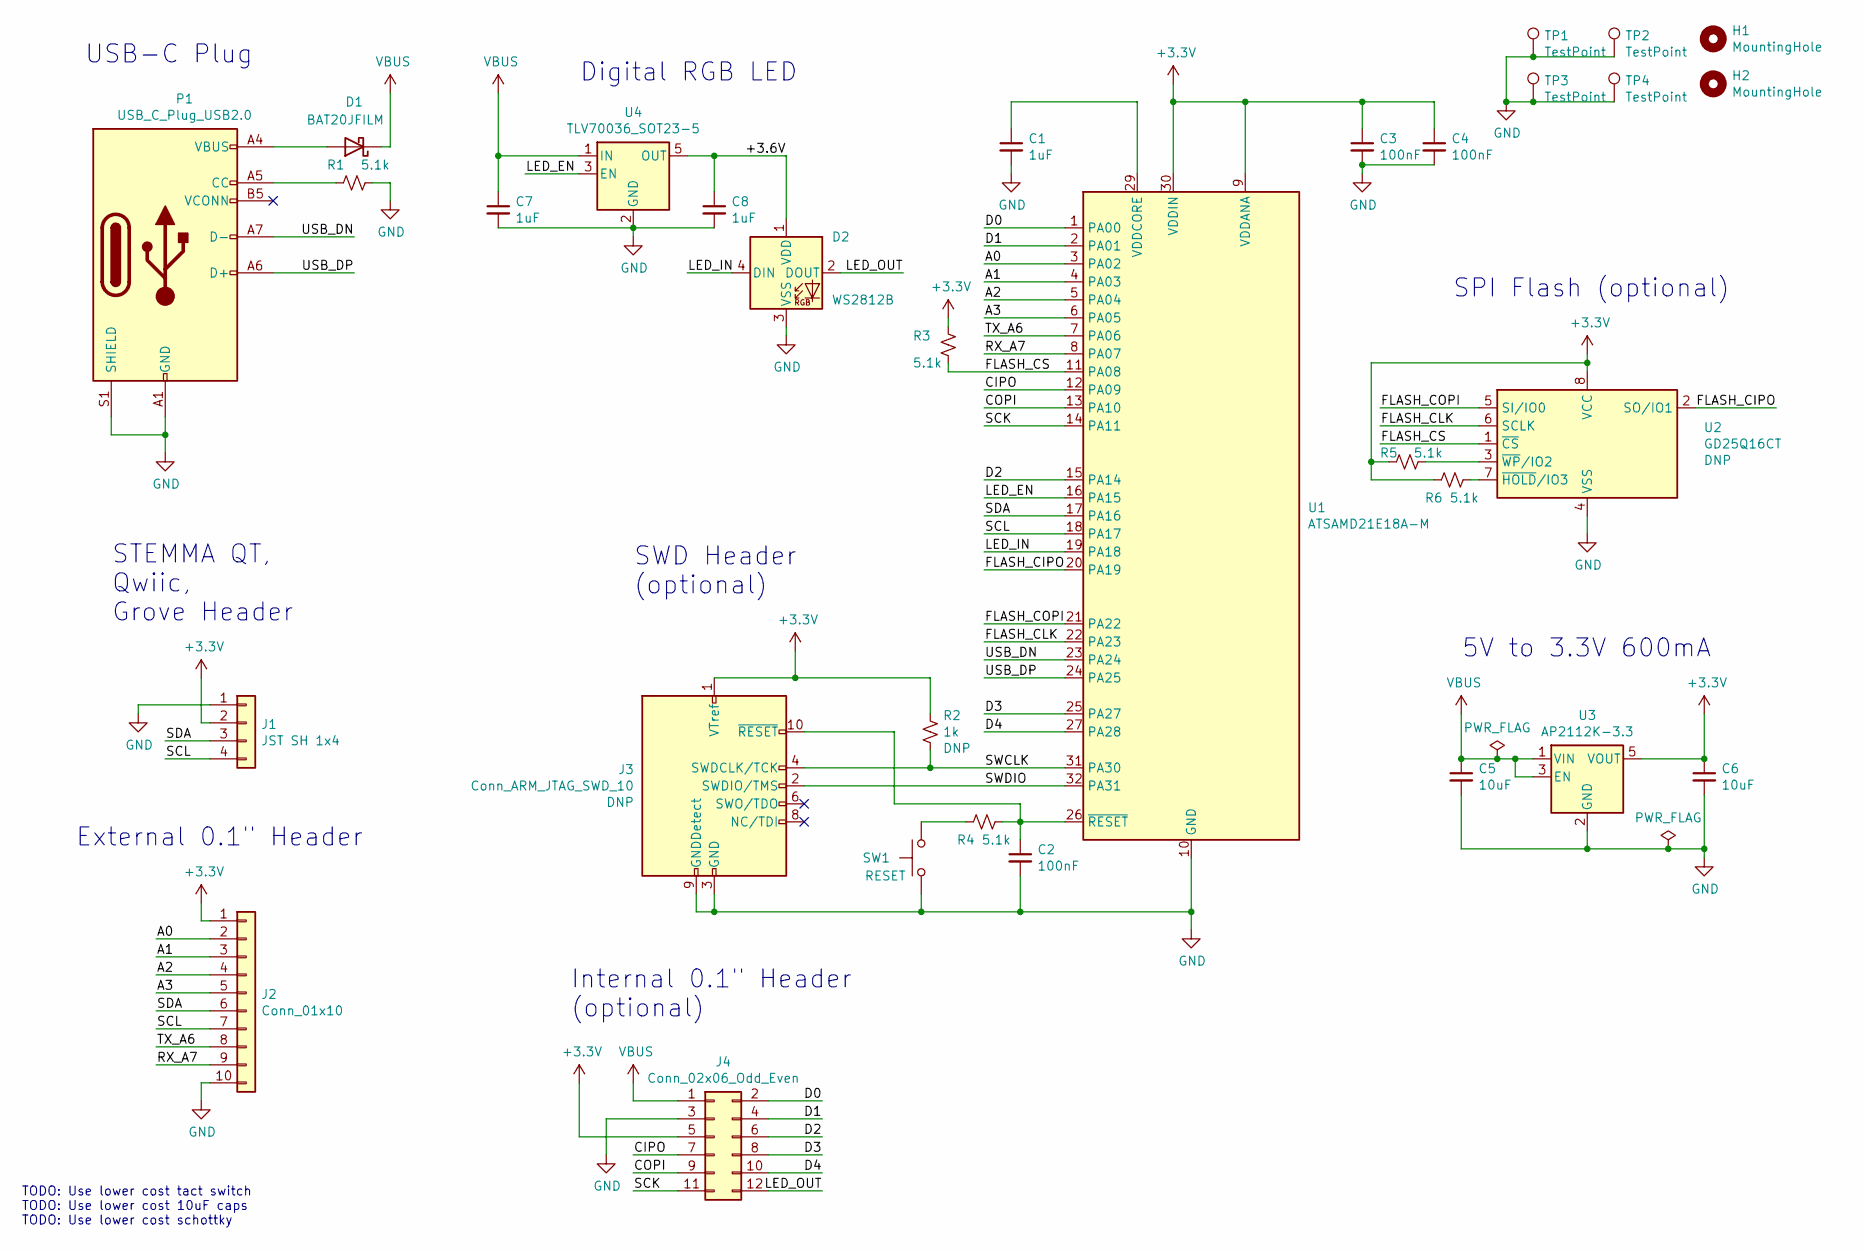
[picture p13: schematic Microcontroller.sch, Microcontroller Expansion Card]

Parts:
C1, C7, C8: 1uF; C_0603_1608Metric
C2, C3, C4: 100nF; C_0603_1608Metric
C5, C6: 10uF; C_0805_2012Metric
D1: BAT20JFILM; D_SOD-323
D2: WS2812B; LED_WS2812B_PLCC4_5.0x5.0mm_P3.2mm
H1, H2: MountingHole; MountingHole_2.2mm_M2
J1: JST SH 1x4; JST_SH_SM04B-SRSS-TB_1x04-1MP_P1.00mm_Horizontal
J2: Conn_01x10; PinSocket_8FM-78-0010-02-146_1x10_P2.54mm_Horizontal_SMD
J3: Conn_ARM_JTAG_SWD_10; PinHeader_2x05_P1.27mm_Vertical_SMD
J4: Conn_02x06_Odd_Even; PinHeader_2x06_P2.54mm_Vertical
P1: USB_C_Plug_USB2.0; USB_C_Plug_Molex_105444
R1, R3, R4, R5, R6: 5.1k; R_0603_1608Metric
R2: 1k; R_0603_1608Metric
SW1: RESET; SW_SPST_B3U-3100P
TP1, TP2, TP3, TP4: TestPoint; TestPoint_Pad_1.5x1.5mm
U1: ATSAMD21E18A-M; QFN-32-1EP_5x5mm_P0.5mm_EP3.6x3.6mm
U2: GD25Q16CT; SOP-8_3.9x4.9mm_P1.27mm
U3: AP2112K-3.3; SOT-23-5
U4: TLV70036_SOT23-5; SOT-23-5

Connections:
+3V3: C3.1, C4.1, C6.1, J1.2, J2.1, J3.1 (VTref), J4.5, R2.1, R3.1, R5.1, R6.1, U1.9 (VDDANA), U1.30 (VDDIN), U2.8 (VCC), U3.5 (VOUT)
/+3.6V: C8.1, D2.1 (VDD), U4.5 (OUT)
/A0: J2.2, U1.3 (PA02)
/A1: J2.3, U1.4 (PA03)
/A2: J2.4, U1.5 (PA04)
/A3: J2.5, U1.6 (PA05)
/CIPO: J4.7, U1.12 (PA09)
/COPI: J4.9, U1.13 (PA10)
/D0: J4.2, U1.1 (PA00)
/D1: J4.4, U1.2 (PA01)
/D2: J4.6, U1.15 (PA14)
/D3: J4.8, U1.25 (PA27)
/D4: J4.10, U1.27 (PA28)
/FLASH_CIPO: U1.20 (PA19), U2.2 (SO/IO1)
/FLASH_CLK: U1.22 (PA23), U2.6 (SCLK)
/FLASH_COPI: U1.21 (PA22), U2.5 (SI/IO0)
/FLASH_CS: R3.2, U1.11 (PA08), U2.1 (~CS)
/LED_EN: U1.16 (PA15), U4.3 (EN)
/LED_IN: D2.4 (DIN), U1.19 (PA18)
/LED_OUT: D2.2 (DOUT), J4.12
/RX_A7: J2.9, U1.8 (PA07)
/SCK: J4.11, U1.14 (PA11)
/SCL: J1.4, J2.7, U1.18 (PA17)
/SDA: J1.3, J2.6, U1.17 (PA16)
/SWCLK: J3.4 (SWDCLK/TCK), R2.2, U1.31 (PA30)
/SWDIO: J3.2 (SWDIO/TMS), U1.32 (PA31)
/TX_A6: J2.8, U1.7 (PA06)
/USB_DN: P1.A7 (D-), U1.23 (PA24)
/USB_DP: P1.A6 (D+), U1.24 (PA25)
GND: C1.2, C2.2, C3.2, C4.2, C5.2, C6.2, C7.2, C8.2, D2.3 (VSS), J1.1, J2.10, J3.3 (GND), J3.5 (GND), J3.9 (GNDDetect), J4.3, P1.A1 (GND), P1.A12 (GND), P1.B1 (GND), P1.B12 (GND), P1.S1 (SHIELD), R1.2, SW1.1, TP1.1, TP2.1, TP3.1, TP4.1, U1.10 (GND), U1.28 (GND), U1.33 (EP), U2.4 (VSS), U3.2 (GND), U4.2 (GND)
unnamed: C1.1, U1.29 (VDDCORE)
unnamed: C2.1, J3.10 (~RESET~), R4.2, U1.26 (~RESET)
unnamed: D1.2 (A), P1.A4 (VBUS), P1.A9 (VBUS), P1.B4 (VBUS), P1.B9 (VBUS)
unnamed: P1.A5 (CC), R1.1
unnamed: R4.1, SW1.2
unnamed: R5.2, U2.3 (~WP~/IO2)
unnamed: R6.2, U2.7 (~HOLD~/IO3)
VBUS: C5.1, C7.1, D1.1 (K), J4.1, U3.1 (VIN), U3.3 (EN), U4.1 (IN)

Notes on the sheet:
TODO: Use lower cost tact switch TODO: Use lower cost 10uF caps TODO: Use lower cost schottky
5V to 3.3V 600mA
SPI Flash (optional)
USB-C Plug
Digital RGB LED
STEMMA QT, Qwiic, Grove Header
SWD Header (optional)
External 0.1" Header
Internal 0.1" Header (optional)

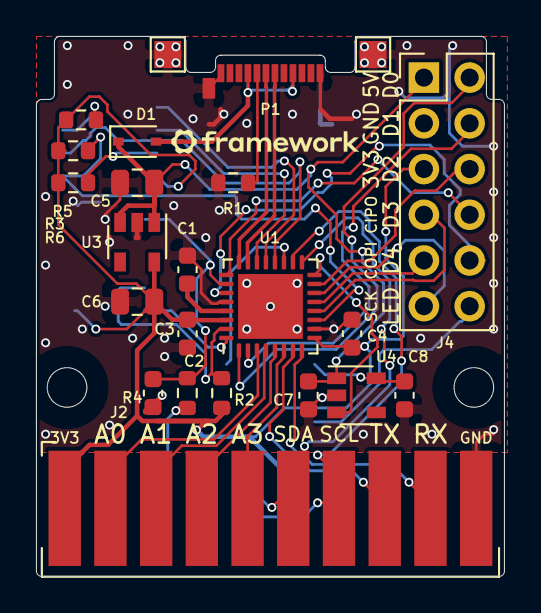
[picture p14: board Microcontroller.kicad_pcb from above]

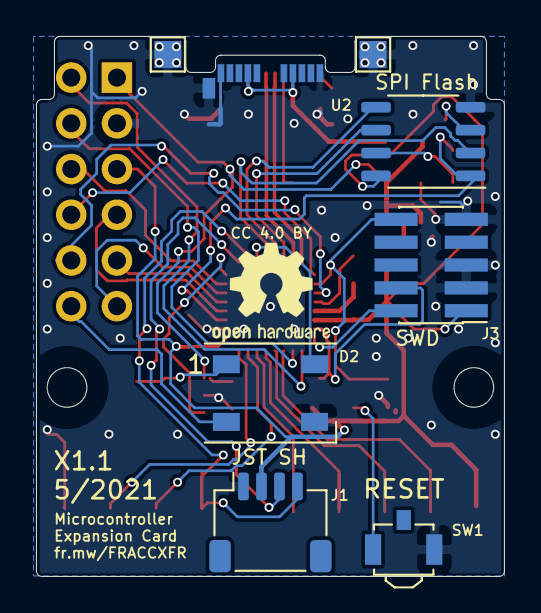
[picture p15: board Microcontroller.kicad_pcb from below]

Board: 2 copper layers, 26.0 x 30.0 mm, 32 parts (7 on the bottom side), 38 nets.

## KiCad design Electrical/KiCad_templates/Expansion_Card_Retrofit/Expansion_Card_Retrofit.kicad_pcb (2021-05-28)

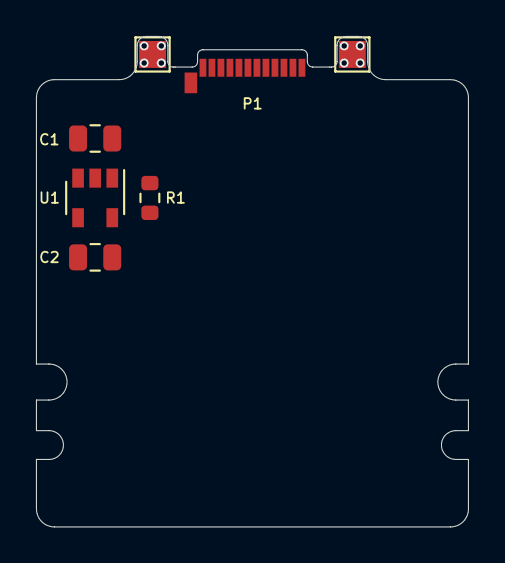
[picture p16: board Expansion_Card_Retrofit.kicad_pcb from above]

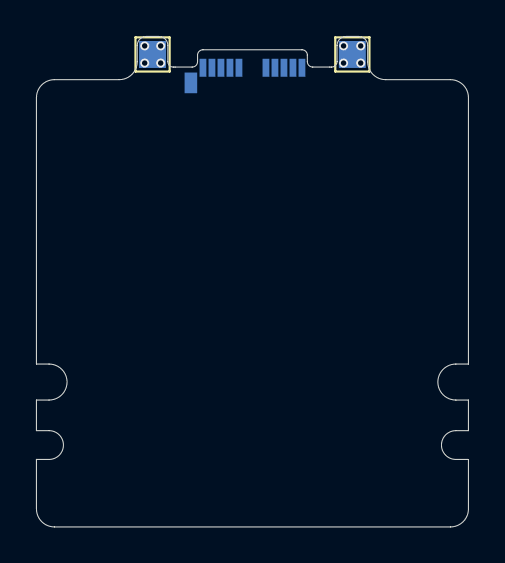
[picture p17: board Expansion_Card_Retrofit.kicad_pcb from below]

Board: 2 copper layers, 24.0 x 27.3 mm, 9 parts (2 on the bottom side), 4 nets, no tracks yet.

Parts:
C1, C2: 10uF; C_0805_2012Metric
P1: USB_C_Plug_USB2.0; USB_C_Plug_Molex_105444
R1: 5.1k; R_0603_1608Metric
TP1, TP2, TP3, TP4: TestPoint; TestPoint_Pad_1.5x1.5mm
U1: AP2112K-3.3; SOT-23-5

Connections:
+3V3: C2.1, U1.5
GND: C1.2, C2.2, P1.A1, P1.A12, P1.B1, P1.B12, P1.S1, R1.2, TP1.1, TP2.1, TP3.1, TP4.1, U1.2
unnamed: P1.A5, R1.1
VBUS: C1.1, P1.A4, P1.A9, P1.B4, P1.B9, U1.1, U1.3

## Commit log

2021-05-17 Mechanical CAD
    [ExpansionCard.scad, ExpansionCard.stl, ExpansionCard_Printable_M2.dxf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]
2021-05-18 Add electrical folder and template
    [Expansion_Card.kicad_pcb, Expansion_Card.sch]
2021-05-18 Add Microcontroller reference design
    [Microcontroller.kicad_pcb, Microcontroller.sch]
2021-05-18 Switch to the GIF
2021-05-28 Retrofit PCBA
    [Expansion_Card_Retrofit.kicad_pcb, Expansion_Card_Retrofit.sch]
2021-05-28 Update test points
    [Expansion_Card_Retrofit.sch]
2021-05-29 Add note about retrofit PCB
2021-06-03 Fab drawing updates
    [Microcontroller.kicad_pcb]
2021-06-10 Switch community URL
2021-06-15 Add a Microcontroller enclosure
    [MicrocontrollerHousing.scad, MicrocontrollerHousing.stl]
